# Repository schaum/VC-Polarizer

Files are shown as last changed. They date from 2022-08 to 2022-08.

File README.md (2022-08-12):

# VC-Polarizer

This VC Polarizer hardware is a shrinked clone of the [Mutable Blinds PCB](http://mutable-instruments.net/modules/blinds) and published under the same license: cc-by-sa-3.0.

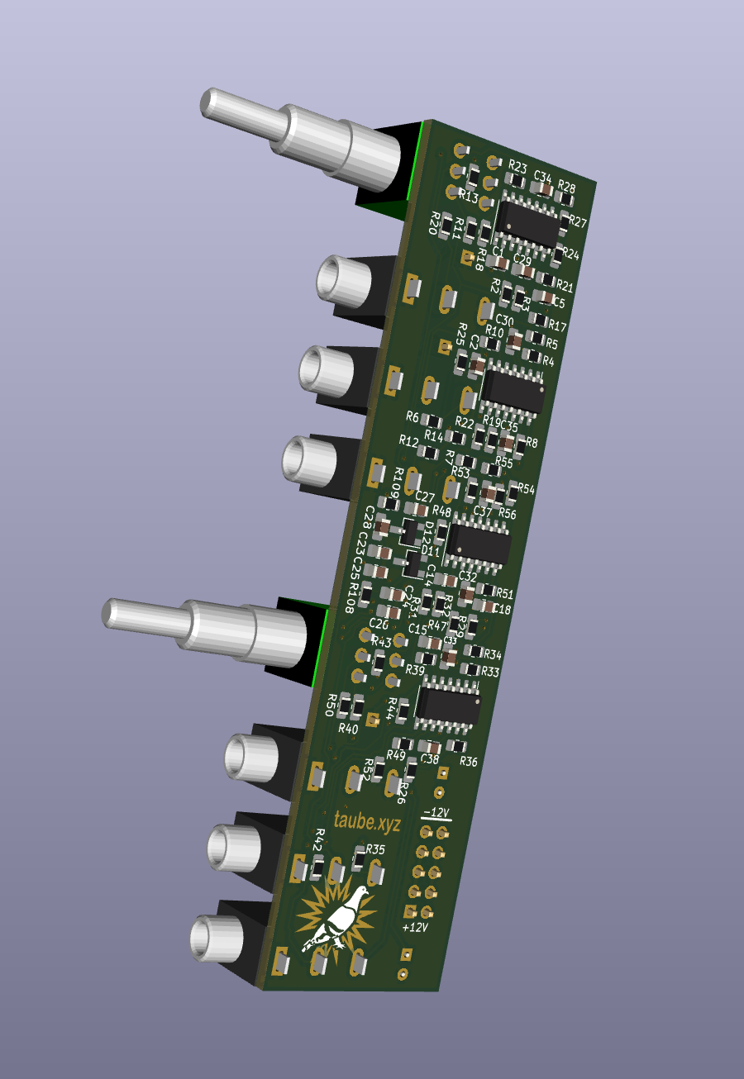
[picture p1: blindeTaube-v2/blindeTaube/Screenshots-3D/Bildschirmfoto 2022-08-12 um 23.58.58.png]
screenshot back side

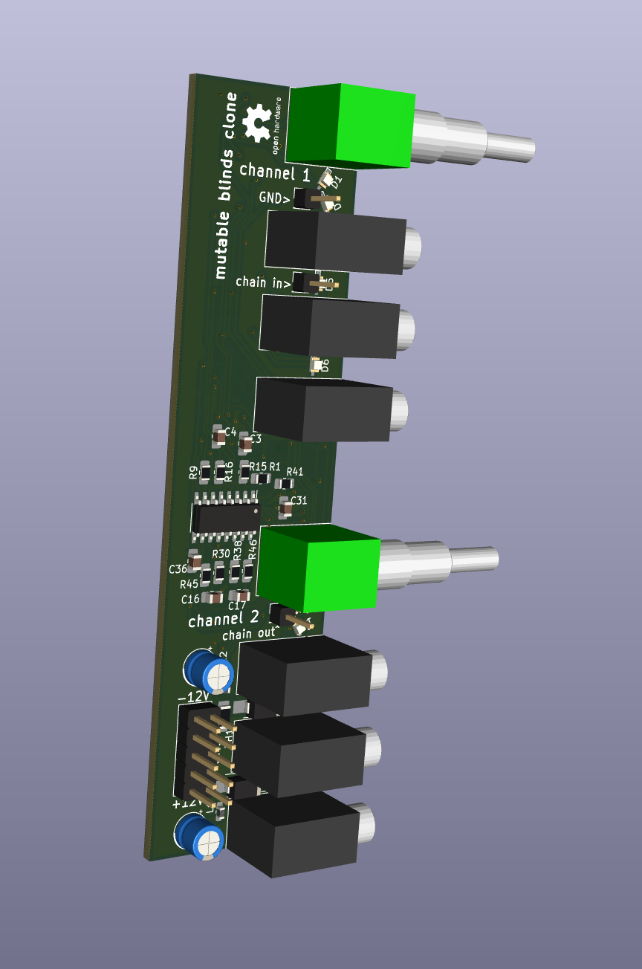
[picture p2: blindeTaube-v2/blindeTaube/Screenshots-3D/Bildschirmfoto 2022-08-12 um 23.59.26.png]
screenshot front side


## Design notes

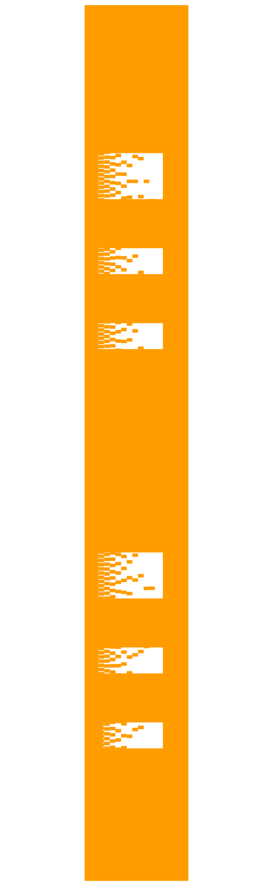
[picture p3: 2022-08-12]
blindeTaube-v2/design/design-FrontPanel-FCU.jpg

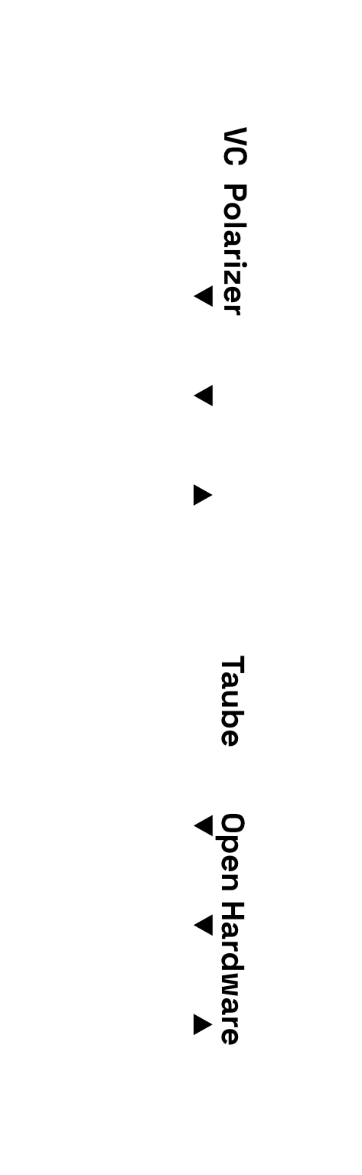
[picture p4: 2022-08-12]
blindeTaube-v2/design/design-FrontPanel-FSilk.jpg

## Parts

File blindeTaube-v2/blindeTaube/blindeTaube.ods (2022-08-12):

Source: | /Users/urbs/Documents/UrbsEleDev-DIY/03Elektronik_Projekte/211212blindeTaube-BlindsKlon/blindeTaube/blindeTaube.kicad_sch
Date: | 2022 April 15, Friday 16:03:00
Tool: | Eeschema (6.0.2-0)
Generator: | /Applications/KiCad/KiCad.app/Contents/SharedSupport/plugins/bom_csv_grouped_by_value.py
Component Count: | 199
Individual Components:
Item | Qty | Reference(s) | Value | LibPart | Footprint | Datasheet
 |  | C1 | 47p | Device:C | Capacitor_SMD:C_0805_2012Metric_Pad1.18x1.45mm_HandSolder | ~
 |  | C2 | 47p | Device:C | Capacitor_SMD:C_0805_2012Metric_Pad1.18x1.45mm_HandSolder | ~
 |  | C3 | 560p | Device:C | Capacitor_SMD:C_0805_2012Metric_Pad1.18x1.45mm_HandSolder | ~
 |  | C4 | 560p | Device:C | Capacitor_SMD:C_0805_2012Metric_Pad1.18x1.45mm_HandSolder | ~
 |  | C5 | 47p | Device:C | Capacitor_SMD:C_0805_2012Metric_Pad1.18x1.45mm_HandSolder | ~
 |  | C6 | 47p | Device:C | Capacitor_SMD:C_0805_2012Metric_Pad1.18x1.45mm_HandSolder | ~
 |  | C7 | 47p | Device:C | Capacitor_SMD:C_0805_2012Metric_Pad1.18x1.45mm_HandSolder | ~
 |  | C8 | 560p | Device:C | Capacitor_SMD:C_0805_2012Metric_Pad1.18x1.45mm_HandSolder | ~
 |  | C9 | 560p | Device:C | Capacitor_SMD:C_0805_2012Metric_Pad1.18x1.45mm_HandSolder | ~
 |  | C10 | 47p | Device:C | Capacitor_SMD:C_0805_2012Metric_Pad1.18x1.45mm_HandSolder | ~
 |  | C11 | 47p | Device:C | Capacitor_SMD:C_0805_2012Metric_Pad1.18x1.45mm_HandSolder | ~
 |  | C12 | 47p | Device:C | Capacitor_SMD:C_0805_2012Metric_Pad1.18x1.45mm_HandSolder | ~
 |  | C13 | 560p | Device:C | Capacitor_SMD:C_0805_2012Metric_Pad1.18x1.45mm_HandSolder | ~
 |  | C14 | 47p | Device:C | Capacitor_SMD:C_0805_2012Metric_Pad1.18x1.45mm_HandSolder | ~
 |  | C15 | 47p | Device:C | Capacitor_SMD:C_0805_2012Metric_Pad1.18x1.45mm_HandSolder | ~
 |  | C16 | 560p | Device:C | Capacitor_SMD:C_0805_2012Metric_Pad1.18x1.45mm_HandSolder | ~
 |  | C17 | 560p | Device:C | Capacitor_SMD:C_0805_2012Metric_Pad1.18x1.45mm_HandSolder | ~
 |  | C18 | 47p | Device:C | Capacitor_SMD:C_0805_2012Metric_Pad1.18x1.45mm_HandSolder | ~
 |  | C19 | 560p | Device:C | Capacitor_SMD:C_0805_2012Metric_Pad1.18x1.45mm_HandSolder | ~
 |  | C20 | 47p | Device:C | Capacitor_SMD:C_0805_2012Metric_Pad1.18x1.45mm_HandSolder | ~
 |  | C21 | 22u | Device:C_Polarized | Capacitor_THT:CP_Radial_D5.0mm_P2.50mm | ~
 |  | C22 | 22u | Device:C_Polarized | Capacitor_THT:CP_Radial_D5.0mm_P2.50mm | ~
 |  | C23 | 100n | Device:C | Capacitor_SMD:C_0805_2012Metric_Pad1.18x1.45mm_HandSolder | ~
 |  | C24 | 100n | Device:C | Capacitor_SMD:C_0805_2012Metric_Pad1.18x1.45mm_HandSolder | ~
 |  | C25 | 100n | Device:C | Capacitor_SMD:C_0805_2012Metric_Pad1.18x1.45mm_HandSolder | ~
 |  | C26 | 100n | Device:C | Capacitor_SMD:C_0805_2012Metric_Pad1.18x1.45mm_HandSolder | ~
 |  | C27 | 100n | Device:C | Capacitor_SMD:C_0805_2012Metric_Pad1.18x1.45mm_HandSolder | ~
 |  | C28 | 100n | Device:C | Capacitor_SMD:C_0805_2012Metric_Pad1.18x1.45mm_HandSolder | ~
 |  | C29 | 100n | Device:C | Capacitor_SMD:C_0805_2012Metric_Pad1.18x1.45mm_HandSolder | ~
 |  | C30 | 100n | Device:C | Capacitor_SMD:C_0805_2012Metric_Pad1.18x1.45mm_HandSolder | ~
 |  | C31 | 100n | Device:C | Capacitor_SMD:C_0805_2012Metric_Pad1.18x1.45mm_HandSolder | ~
 |  | C32 | 100n | Device:C | Capacitor_SMD:C_0805_2012Metric_Pad1.18x1.45mm_HandSolder | ~
 |  | C33 | 100n | Device:C | Capacitor_SMD:C_0805_2012Metric_Pad1.18x1.45mm_HandSolder | ~
 |  | C34 | 100n | Device:C | Capacitor_SMD:C_0805_2012Metric_Pad1.18x1.45mm_HandSolder | ~
 |  | C35 | 100n | Device:C | Capacitor_SMD:C_0805_2012Metric_Pad1.18x1.45mm_HandSolder | ~
 |  | C36 | 100n | Device:C | Capacitor_SMD:C_0805_2012Metric_Pad1.18x1.45mm_HandSolder | ~
 |  | C37 | 100n | Device:C | Capacitor_SMD:C_0805_2012Metric_Pad1.18x1.45mm_HandSolder | ~
 |  | C38 | 100n | Device:C | Capacitor_SMD:C_0805_2012Metric_Pad1.18x1.45mm_HandSolder | ~
 |  | C39 | 100n | Device:C | Capacitor_SMD:C_0805_2012Metric_Pad1.18x1.45mm_HandSolder | ~
 |  | C40 | 100n | Device:C | Capacitor_SMD:C_0805_2012Metric_Pad1.18x1.45mm_HandSolder | ~
 |  | C41 | 100n | Device:C | Capacitor_SMD:C_0805_2012Metric_Pad1.18x1.45mm_HandSolder | ~
 |  | C42 | 100n | Device:C | Capacitor_SMD:C_0805_2012Metric_Pad1.18x1.45mm_HandSolder | ~
 |  | C43 | 100n | Device:C | Capacitor_SMD:C_0805_2012Metric_Pad1.18x1.45mm_HandSolder | ~
 |  | C44 | 100n | Device:C | Capacitor_SMD:C_0805_2012Metric_Pad1.18x1.45mm_HandSolder | ~
 |  | C45 | 100n | Device:C | Capacitor_SMD:C_0805_2012Metric_Pad1.18x1.45mm_HandSolder | ~
 |  | C46 | 100n | Device:C | Capacitor_SMD:C_0805_2012Metric_Pad1.18x1.45mm_HandSolder | ~
 |  | C47 | 100n | Device:C | Capacitor_SMD:C_0805_2012Metric_Pad1.18x1.45mm_HandSolder | ~
 |  | C48 | 100n | Device:C | Capacitor_SMD:C_0805_2012Metric_Pad1.18x1.45mm_HandSolder | ~
 |  | D1 | LED_Dual_AKKA>AK-vertauscht-aber geht so | Device:LED_Dual_AKKA | LED_SMD:LED_Avago_PLCC4_3.2x2.8mm_CW | ~
 |  | D2 | LED_Dual_AKKA>AK-vertauscht-aber geht so | Device:LED_Dual_AKKA | LED_SMD:LED_Avago_PLCC4_3.2x2.8mm_CW | ~
 |  | D3 | LED_Dual_AKKA>AK-vertauscht-aber geht so | Device:LED_Dual_AKKA | LED_SMD:LED_Avago_PLCC4_3.2x2.8mm_CW | ~
 |  | D4 | LED_Dual_AKKA>AK-vertauscht-aber geht so | Device:LED_Dual_AKKA | LED_SMD:LED_Avago_PLCC4_3.2x2.8mm_CW | ~
 |  | D5 | LED_Dual_AKKA>AK-vertauscht-aber geht so | Device:LED_Dual_AKKA | LED_SMD:LED_Avago_PLCC4_3.2x2.8mm_CW | ~
 |  | D6 | LED_Dual_AKKA>AK-vertauscht-aber geht so | Device:LED_Dual_AKKA | LED_SMD:LED_Avago_PLCC4_3.2x2.8mm_CW | ~
 |  | D7 | LED_Dual_AKKA>AK-vertauscht-aber geht so | Device:LED_Dual_AKKA | LED_SMD:LED_Avago_PLCC4_3.2x2.8mm_CW | ~
 |  | D8 | LED_Dual_AKKA>AK-vertauscht-aber geht so | Device:LED_Dual_AKKA | LED_SMD:LED_Avago_PLCC4_3.2x2.8mm_CW | ~
 |  | D9 | D | Device:D | Diode_SMD:D_MELF_Handsoldering | ~
 |  | D10 | D | Device:D | Diode_SMD:D_MELF_Handsoldering | ~
 |  | D11 | LM4040DBZ-10 | Reference_Voltage:LM4040DBZ-10 | Package_TO_SOT_SMD:SOT-23_Handsoldering | http://www.ti.com/lit/ds/symlink/lm4040-n.pdf
 |  | D12 | LM4040DBZ-10 | Reference_Voltage:LM4040DBZ-10 | Package_TO_SOT_SMD:SOT-23_Handsoldering | http://www.ti.com/lit/ds/symlink/lm4040-n.pdf
 |  | J1 | AudioJack2_SwitchT | Connector:AudioJack2_SwitchT | urbsLib:Jack_3.5mm_QingPu_distant | ~
 |  | J2 | AudioJack2_SwitchT | Connector:AudioJack2_SwitchT | urbsLib:Jack_3.5mm_QingPu_distant | ~
 |  | J3 | AudioJack2_SwitchT | Connector:AudioJack2_SwitchT | urbsLib:Jack_3.5mm_QingPu_distant | ~
 |  | J4 | AudioJack2_SwitchT | Connector:AudioJack2_SwitchT | urbsLib:Jack_3.5mm_QingPu_distant | ~
 |  | J5 | AudioJack2_SwitchT | Connector:AudioJack2_SwitchT | urbsLib:Jack_3.5mm_QingPu_distant | ~
 |  | J6 | AudioJack2_SwitchT | Connector:AudioJack2_SwitchT | urbsLib:Jack_3.5mm_QingPu_distant | ~
 |  | J7 | AudioJack2_SwitchT | Connector:AudioJack2_SwitchT | urbsLib:Jack_3.5mm_QingPu_distant | ~
 |  | J8 | AudioJack2_SwitchT | Connector:AudioJack2_SwitchT | urbsLib:Jack_3.5mm_QingPu_distant | ~
 |  | J9 | AudioJack2_SwitchT | Connector:AudioJack2_SwitchT | urbsLib:Jack_3.5mm_QingPu_distant | ~
 |  | J10 | AudioJack2_SwitchT | Connector:AudioJack2_SwitchT | urbsLib:Jack_3.5mm_QingPu_distant | ~
 |  | J11 | AudioJack2_SwitchT | Connector:AudioJack2_SwitchT | urbsLib:Jack_3.5mm_QingPu_distant | ~
 |  | J12 | AudioJack2_SwitchT | Connector:AudioJack2_SwitchT | urbsLib:Jack_3.5mm_QingPu_distant | ~
 |  | J13 | Conn_02x05_Odd_Even | Connector_Generic:Conn_02x05_Odd_Even | Connector_PinHeader_2.54mm:PinHeader_2x05_P2.54mm_Vertical | ~
 |  | L1 | 742792664 | Device:L | Inductor_SMD:L_1008_2520Metric_Pad1.43x2.20mm_HandSolder | ~
 |  | L2 | 742792664 | Device:L | Inductor_SMD:L_1008_2520Metric_Pad1.43x2.20mm_HandSolder | ~
 |  | R1 | 100k | Device:R | Resistor_SMD:R_0805_2012Metric_Pad1.20x1.40mm_HandSolder | ~
 |  | R2 | 100k | Device:R | Resistor_SMD:R_0805_2012Metric_Pad1.20x1.40mm_HandSolder | ~
 |  | R3 | 100k | Device:R | Resistor_SMD:R_0805_2012Metric_Pad1.20x1.40mm_HandSolder | ~
 |  | R4 | 4k3 | Device:R | Resistor_SMD:R_0805_2012Metric_Pad1.20x1.40mm_HandSolder | ~
 |  | R5 | 4k3 | Device:R | Resistor_SMD:R_0805_2012Metric_Pad1.20x1.40mm_HandSolder | ~
 |  | R6 | 100k | Device:R | Resistor_SMD:R_0805_2012Metric_Pad1.20x1.40mm_HandSolder | ~
 |  | R7 | 3k9 | Device:R | Resistor_SMD:R_0805_2012Metric_Pad1.20x1.40mm_HandSolder | ~
 |  | R8 | 4k3 | Device:R | Resistor_SMD:R_0805_2012Metric_Pad1.20x1.40mm_HandSolder | ~
 |  | R9 | 33k2 | Device:R | Resistor_SMD:R_0805_2012Metric_Pad1.20x1.40mm_HandSolder | ~
 |  | R10 | 66k5 | Device:R | Resistor_SMD:R_0805_2012Metric_Pad1.20x1.40mm_HandSolder | ~
 |  | R11 | 205k | Device:R | Resistor_SMD:R_0805_2012Metric_Pad1.20x1.40mm_HandSolder | ~
 |  | R12 | 402 | Device:R | Resistor_SMD:R_0805_2012Metric_Pad1.20x1.40mm_HandSolder | ~
 |  | R13 | 100k | Device:R | Resistor_SMD:R_0805_2012Metric_Pad1.20x1.40mm_HandSolder | ~
 |  | R14 | 1M | Device:R | Resistor_SMD:R_0805_2012Metric_Pad1.20x1.40mm_HandSolder | ~
 |  | R15 | 510 | Device:R | Resistor_SMD:R_0805_2012Metric_Pad1.20x1.40mm_HandSolder | ~
 |  | R16 | 510 | Device:R | Resistor_SMD:R_0805_2012Metric_Pad1.20x1.40mm_HandSolder | ~
 |  | R17 | 33k2 | Device:R | Resistor_SMD:R_0805_2012Metric_Pad1.20x1.40mm_HandSolder | ~
 |  | R18 | 100k | Device:R | Resistor_SMD:R_0805_2012Metric_Pad1.20x1.40mm_HandSolder | ~
 |  | R19 | 1M | Device:R | Resistor_SMD:R_0805_2012Metric_Pad1.20x1.40mm_HandSolder | ~
 |  | R20 | 100k | Device:R | Resistor_SMD:R_0805_2012Metric_Pad1.20x1.40mm_HandSolder | ~
 |  | R21 | 100k | Device:R | Resistor_SMD:R_0805_2012Metric_Pad1.20x1.40mm_HandSolder | ~
 |  | R22 | 1k2 | Device:R | Resistor_SMD:R_0805_2012Metric_Pad1.20x1.40mm_HandSolder | ~
 |  | R23 | 100k | Device:R | Resistor_SMD:R_0805_2012Metric_Pad1.20x1.40mm_HandSolder | ~
 |  | R24 | 1M | Device:R | Resistor_SMD:R_0805_2012Metric_Pad1.20x1.40mm_HandSolder | ~
 |  | R25 | 66k5 | Device:R | Resistor_SMD:R_0805_2012Metric_Pad1.20x1.40mm_HandSolder | ~
 |  | R26 | 100k | Device:R | Resistor_SMD:R_0805_2012Metric_Pad1.20x1.40mm_HandSolder | ~
 |  | R27 | 1M | Device:R | Resistor_SMD:R_0805_2012Metric_Pad1.20x1.40mm_HandSolder | ~
 |  | R28 | 1k2 | Device:R | Resistor_SMD:R_0805_2012Metric_Pad1.20x1.40mm_HandSolder | ~
 |  | R29 | 66k5 | Device:R | Resistor_SMD:R_0805_2012Metric_Pad1.20x1.40mm_HandSolder | ~
 |  | R30 | 100k | Device:R | Resistor_SMD:R_0805_2012Metric_Pad1.20x1.40mm_HandSolder | ~
 |  | R31 | 100k | Device:R | Resistor_SMD:R_0805_2012Metric_Pad1.20x1.40mm_HandSolder | ~
 |  | R32 | 100k | Device:R | Resistor_SMD:R_0805_2012Metric_Pad1.20x1.40mm_HandSolder | ~
 |  | R33 | 4k3 | Device:R | Resistor_SMD:R_0805_2012Metric_Pad1.20x1.40mm_HandSolder | ~
 |  | R34 | 4k3 | Device:R | Resistor_SMD:R_0805_2012Metric_Pad1.20x1.40mm_HandSolder | ~
 |  | R35 | 100k | Device:R | Resistor_SMD:R_0805_2012Metric_Pad1.20x1.40mm_HandSolder | ~
 |  | R36 | 3k9 | Device:R | Resistor_SMD:R_0805_2012Metric_Pad1.20x1.40mm_HandSolder | ~
 |  | R37 | 4k3 | Device:R | Resistor_SMD:R_0805_2012Metric_Pad1.20x1.40mm_HandSolder | ~
 |  | R38 | 33k2 | Device:R | Resistor_SMD:R_0805_2012Metric_Pad1.20x1.40mm_HandSolder | ~
 |  | R39 | 66k5 | Device:R | Resistor_SMD:R_0805_2012Metric_Pad1.20x1.40mm_HandSolder | ~
 |  | R40 | 205k | Device:R | Resistor_SMD:R_0805_2012Metric_Pad1.20x1.40mm_HandSolder | ~
 |  | R41 | DNP | Device:R | Resistor_SMD:R_0805_2012Metric_Pad1.20x1.40mm_HandSolder | ~
 |  | R42 | 402 | Device:R | Resistor_SMD:R_0805_2012Metric_Pad1.20x1.40mm_HandSolder | ~
 |  | R43 | 100k | Device:R | Resistor_SMD:R_0805_2012Metric_Pad1.20x1.40mm_HandSolder | ~
 |  | R44 | 1M | Device:R | Resistor_SMD:R_0805_2012Metric_Pad1.20x1.40mm_HandSolder | ~
 |  | R45 | 510 | Device:R | Resistor_SMD:R_0805_2012Metric_Pad1.20x1.40mm_HandSolder | ~
 |  | R46 | 510 | Device:R | Resistor_SMD:R_0805_2012Metric_Pad1.20x1.40mm_HandSolder | ~
 |  | R47 | 33k2 | Device:R | Resistor_SMD:R_0805_2012Metric_Pad1.20x1.40mm_HandSolder | ~
 |  | R48 | 100k | Device:R | Resistor_SMD:R_0805_2012Metric_Pad1.20x1.40mm_HandSolder | ~
 |  | R49 | 1M | Device:R | Resistor_SMD:R_0805_2012Metric_Pad1.20x1.40mm_HandSolder | ~
 |  | R50 | 100k | Device:R | Resistor_SMD:R_0805_2012Metric_Pad1.20x1.40mm_HandSolder | ~
 |  | R51 | 100k | Device:R | Resistor_SMD:R_0805_2012Metric_Pad1.20x1.40mm_HandSolder | ~
 |  | R52 | 1k2 | Device:R | Resistor_SMD:R_0805_2012Metric_Pad1.20x1.40mm_HandSolder | ~
 |  | R53 | 100k | Device:R | Resistor_SMD:R_0805_2012Metric_Pad1.20x1.40mm_HandSolder | ~
 |  | R54 | 1M | Device:R | Resistor_SMD:R_0805_2012Metric_Pad1.20x1.40mm_HandSolder | ~
 |  | R55 | 1M | Device:R | Resistor_SMD:R_0805_2012Metric_Pad1.20x1.40mm_HandSolder | ~
 |  | R56 | 1k2 | Device:R | Resistor_SMD:R_0805_2012Metric_Pad1.20x1.40mm_HandSolder | ~
 |  | R57 | 100k | Device:R | Resistor_SMD:R_0805_2012Metric_Pad1.20x1.40mm_HandSolder | ~
 |  | R58 | 100k | Device:R | Resistor_SMD:R_0805_2012Metric_Pad1.20x1.40mm_HandSolder | ~
 |  | R59 | 4k3 | Device:R | Resistor_SMD:R_0805_2012Metric_Pad1.20x1.40mm_HandSolder | ~
 |  | R60 | 4k3 | Device:R | Resistor_SMD:R_0805_2012Metric_Pad1.20x1.40mm_HandSolder | ~
 |  | R61 | 100k | Device:R | Resistor_SMD:R_0805_2012Metric_Pad1.20x1.40mm_HandSolder | ~
 |  | R62 | 3k9 | Device:R | Resistor_SMD:R_0805_2012Metric_Pad1.20x1.40mm_HandSolder | ~
 |  | R63 | 4k3 | Device:R | Resistor_SMD:R_0805_2012Metric_Pad1.20x1.40mm_HandSolder | ~
 |  | R64 | 33k2 | Device:R | Resistor_SMD:R_0805_2012Metric_Pad1.20x1.40mm_HandSolder | ~
 |  | R65 | 66k5 | Device:R | Resistor_SMD:R_0805_2012Metric_Pad1.20x1.40mm_HandSolder | ~
 |  | R66 | 205k | Device:R | Resistor_SMD:R_0805_2012Metric_Pad1.20x1.40mm_HandSolder | ~
 |  | R67 | 402 | Device:R | Resistor_SMD:R_0805_2012Metric_Pad1.20x1.40mm_HandSolder | ~
 |  | R68 | 100k | Device:R | Resistor_SMD:R_0805_2012Metric_Pad1.20x1.40mm_HandSolder | ~
 |  | R69 | 1M | Device:R | Resistor_SMD:R_0805_2012Metric_Pad1.20x1.40mm_HandSolder | ~
 |  | R70 | 510 | Device:R | Resistor_SMD:R_0805_2012Metric_Pad1.20x1.40mm_HandSolder | ~
 |  | R71 | 510 | Device:R | Resistor_SMD:R_0805_2012Metric_Pad1.20x1.40mm_HandSolder | ~
 |  | R72 | 33k2 | Device:R | Resistor_SMD:R_0805_2012Metric_Pad1.20x1.40mm_HandSolder | ~
 |  | R73 | 100k | Device:R | Resistor_SMD:R_0805_2012Metric_Pad1.20x1.40mm_HandSolder | ~
 |  | R74 | 1M | Device:R | Resistor_SMD:R_0805_2012Metric_Pad1.20x1.40mm_HandSolder | ~
 |  | R75 | 100k | Device:R | Resistor_SMD:R_0805_2012Metric_Pad1.20x1.40mm_HandSolder | ~
 |  | R76 | 100k | Device:R | Resistor_SMD:R_0805_2012Metric_Pad1.20x1.40mm_HandSolder | ~
 |  | R77 | 1k2 | Device:R | Resistor_SMD:R_0805_2012Metric_Pad1.20x1.40mm_HandSolder | ~
 |  | R78 | 100k | Device:R | Resistor_SMD:R_0805_2012Metric_Pad1.20x1.40mm_HandSolder | ~
 |  | R79 | 1M | Device:R | Resistor_SMD:R_0805_2012Metric_Pad1.20x1.40mm_HandSolder | ~
 |  | R80 | 1M | Device:R | Resistor_SMD:R_0805_2012Metric_Pad1.20x1.40mm_HandSolder | ~
 |  | R81 | 1k2 | Device:R | Resistor_SMD:R_0805_2012Metric_Pad1.20x1.40mm_HandSolder | ~
 |  | R82 | 66k5 | Device:R | Resistor_SMD:R_0805_2012Metric_Pad1.20x1.40mm_HandSolder | ~
 |  | R83 | 100k | Device:R | Resistor_SMD:R_0805_2012Metric_Pad1.20x1.40mm_HandSolder | ~
 |  | R84 | 100k | Device:R | Resistor_SMD:R_0805_2012Metric_Pad1.20x1.40mm_HandSolder | ~
 |  | R85 | 100k | Device:R | Resistor_SMD:R_0805_2012Metric_Pad1.20x1.40mm_HandSolder | ~
 |  | R86 | 4k3 | Device:R | Resistor_SMD:R_0805_2012Metric_Pad1.20x1.40mm_HandSolder | ~
 |  | R87 | 4k3 | Device:R | Resistor_SMD:R_0805_2012Metric_Pad1.20x1.40mm_HandSolder | ~
 |  | R88 | 100k | Device:R | Resistor_SMD:R_0805_2012Metric_Pad1.20x1.40mm_HandSolder | ~
 |  | R89 | 33k2 | Device:R | Resistor_SMD:R_0805_2012Metric_Pad1.20x1.40mm_HandSolder | ~
 |  | R90 | 66k5 | Device:R | Resistor_SMD:R_0805_2012Metric_Pad1.20x1.40mm_HandSolder | ~
 |  | R91 | 205k | Device:R | Resistor_SMD:R_0805_2012Metric_Pad1.20x1.40mm_HandSolder | ~
 |  | R92 | DNP | Device:R | Resistor_SMD:R_0805_2012Metric_Pad1.20x1.40mm_HandSolder | ~
 |  | R93 | 402 | Device:R | Resistor_SMD:R_0805_2012Metric_Pad1.20x1.40mm_HandSolder | ~
 |  | R94 | 100k | Device:R | Resistor_SMD:R_0805_2012Metric_Pad1.20x1.40mm_HandSolder | ~
 |  | R95 | 1M | Device:R | Resistor_SMD:R_0805_2012Metric_Pad1.20x1.40mm_HandSolder | ~
 |  | R96 | 510 | Device:R | Resistor_SMD:R_0805_2012Metric_Pad1.20x1.40mm_HandSolder | ~
 |  | R97 | 510 | Device:R | Resistor_SMD:R_0805_2012Metric_Pad1.20x1.40mm_HandSolder | ~
 |  | R98 | 33k2 | Device:R | Resistor_SMD:R_0805_2012Metric_Pad1.20x1.40mm_HandSolder | ~
 |  | R99 | 100k | Device:R | Resistor_SMD:R_0805_2012Metric_Pad1.20x1.40mm_HandSolder | ~
 |  | R100 | 1M | Device:R | Resistor_SMD:R_0805_2012Metric_Pad1.20x1.40mm_HandSolder | ~
 |  | R101 | 100k | Device:R | Resistor_SMD:R_0805_2012Metric_Pad1.20x1.40mm_HandSolder | ~
 |  | R102 | 100k | Device:R | Resistor_SMD:R_0805_2012Metric_Pad1.20x1.40mm_HandSolder | ~
 |  | R103 | 1k2 | Device:R | Resistor_SMD:R_0805_2012Metric_Pad1.20x1.40mm_HandSolder | ~
 |  | R104 | 100k | Device:R | Resistor_SMD:R_0805_2012Metric_Pad1.20x1.40mm_HandSolder | ~
 |  | R105 | 1M | Device:R | Resistor_SMD:R_0805_2012Metric_Pad1.20x1.40mm_HandSolder | ~
 |  | R106 | 1M | Device:R | Resistor_SMD:R_0805_2012Metric_Pad1.20x1.40mm_HandSolder | ~
 |  | R107 | 1k2 | Device:R | Resistor_SMD:R_0805_2012Metric_Pad1.20x1.40mm_HandSolder | ~
 |  | R108 | 1k2 | Device:R | Resistor_SMD:R_0805_2012Metric_Pad1.20x1.40mm_HandSolder | ~
 |  | R109 | 1k2 | Device:R | Resistor_SMD:R_0805_2012Metric_Pad1.20x1.40mm_HandSolder | ~
 |  | RV1 | 10kB | Device:R_Potentiometer_Dual_Separate | urbsLib:RK097-dual-top | ~
 |  | RV2 | 10kB | Device:R_Potentiometer_Dual_Separate | urbsLib:RK097-dual-top | ~
 |  | RV3 | 10kB | Device:R_Potentiometer_Dual_Separate | urbsLib:RK097-dual-top | ~
 |  | RV4 | 10kB | Device:R_Potentiometer_Dual_Separate | urbsLib:RK097-dual-top | ~
 |  | TH1 | Thermistor_PTC | Device:Thermistor_PTC | Resistor_SMD:R_0805_2012Metric_Pad1.20x1.40mm_HandSolder | ~
 |  | U1 | OPA4171 | Amplifier_Operational:OPA4134 | Package_SO:TSSOP-14_4.4x5mm_P0.65mm | http://www.ti.com/lit/ds/symlink/opa134.pdf
 |  | U2 | OPA4171 | Amplifier_Operational:OPA4134 | Package_SO:TSSOP-14_4.4x5mm_P0.65mm | http://www.ti.com/lit/ds/symlink/opa134.pdf
 |  | U3 | SSI2164 | Audio:SSI2164 | Package_SO:SOIC-16_3.9x9.9mm_P1.27mm | http://www.soundsemiconductor.com/downloads/ssi2164datasheet.pdf
 |  | U4 | OPA4171 | Amplifier_Operational:OPA4134 | Package_SO:TSSOP-14_4.4x5mm_P0.65mm | http://www.ti.com/lit/ds/symlink/opa134.pdf
 |  | U5 | OPA4171 | Amplifier_Operational:OPA4134 | Package_SO:TSSOP-14_4.4x5mm_P0.65mm | http://www.ti.com/lit/ds/symlink/opa134.pdf
 |  | U6 | OPA4171 | Amplifier_Operational:OPA4134 | Package_SO:TSSOP-14_4.4x5mm_P0.65mm | http://www.ti.com/lit/ds/symlink/opa134.pdf
 |  | U7 | OPA4171 | Amplifier_Operational:OPA4134 | Package_SO:TSSOP-14_4.4x5mm_P0.65mm | http://www.ti.com/lit/ds/symlink/opa134.pdf
 |  | U8 | SSI2164 | Audio:SSI2164 | Package_SO:SOIC-16_3.9x9.9mm_P1.27mm | http://www.soundsemiconductor.com/downloads/ssi2164datasheet.pdf
 |  | U9 | OPA4171 | Amplifier_Operational:OPA4134 | Package_SO:TSSOP-14_4.4x5mm_P0.65mm | http://www.ti.com/lit/ds/symlink/opa134.pdf
 |  | U10 | OPA4171 | Amplifier_Operational:OPA4134 | Package_SO:TSSOP-14_4.4x5mm_P0.65mm | http://www.ti.com/lit/ds/symlink/opa134.pdf
Collated Components:
Item | Qty | Reference(s) | Value | LibPart | Footprint | Datasheet
1 | 12 | C1, C2, C5, C6, C7, C10, C11, C12, C14, C15, C18, C20 | 47p | Device:C | Capacitor_SMD:C_0805_2012Metric_Pad1.18x1.45mm_HandSolder | ~
2 | 8 | C3, C4, C8, C9, C13, C16, C17, C19 | 560p | Device:C | Capacitor_SMD:C_0805_2012Metric_Pad1.18x1.45mm_HandSolder | ~
3 | 2 | C21, C22 | 22u | Device:C_Polarized | Capacitor_THT:CP_Radial_D5.0mm_P2.50mm | ~
4 | 26 | C23, C24, C25, C26, C27, C28, C29, C30, C31, C32, C33, C34, C35, C36, C37, C38, C39, C40, C41, C42, C43, C44, C45, C46, C47, C48 | 100n | Device:C | Capacitor_SMD:C_0805_2012Metric_Pad1.18x1.45mm_HandSolder | ~
5 | 8 | D1, D2, D3, D4, D5, D6, D7, D8 | LED_Dual_AKKA>AK-vertauscht-aber geht so | Device:LED_Dual_AKKA | LED_SMD:LED_Avago_PLCC4_3.2x2.8mm_CW | ~
6 | 2 | D9, D10 | D | Device:D | Diode_SMD:D_MELF_Handsoldering | ~
7 | 2 | D11, D12 | LM4040DBZ-10 | Reference_Voltage:LM4040DBZ-10 | Package_TO_SOT_SMD:SOT-23_Handsoldering | http://www.ti.com/lit/ds/symlink/lm4040-n.pdf
8 | 12 | J1, J2, J3, J4, J5, J6, J7, J8, J9, J10, J11, J12 | AudioJack2_SwitchT | Connector:AudioJack2_SwitchT | urbsLib:Jack_3.5mm_QingPu_distant | ~
9 | 1 | J13 | Conn_02x05_Odd_Even | Connector_Generic:Conn_02x05_Odd_Even | Connector_PinHeader_2.54mm:PinHeader_2x05_P2.54mm_Vertical | ~
10 | 2 | L1, L2 | 742792664 | Device:L | Inductor_SMD:L_1008_2520Metric_Pad1.43x2.20mm_HandSolder | ~
11 | 36 | R1, R2, R3, R6, R13, R18, R20, R21, R23, R26, R30, R31, R32, R35, R43, R48, R50, R51, R53, R57, R58, R61, R68, R73, R75, R76, R78, R83, R84, R85, R88, R94, R99, R101, R102, R104 | 100k | Device:R | Resistor_SMD:R_0805_2012Metric_Pad1.20x1.40mm_HandSolder | ~
12 | 11 | R4, R5, R8, R33, R34, R37, R59, R60, R63, R86, R87 | 4k3 | Device:R | Resistor_SMD:R_0805_2012Metric_Pad1.20x1.40mm_HandSolder | ~
13 | 3 | R7, R36, R62 | 3k9 | Device:R | Resistor_SMD:R_0805_2012Metric_Pad1.20x1.40mm_HandSolder | ~
14 | 8 | R9, R17, R38, R47, R64, R72, R89, R98 | 33k2 | Device:R | Resistor_SMD:R_0805_2012Metric_Pad1.20x1.40mm_HandSolder | ~
15 | 7 | R10, R25, R29, R39, R65, R82, R90 | 66k5 | Device:R | Resistor_SMD:R_0805_2012Metric_Pad1.20x1.40mm_HandSolder | ~
16 | 4 | R11, R40, R66, R91 | 205k | Device:R | Resistor_SMD:R_0805_2012Metric_Pad1.20x1.40mm_HandSolder | ~
17 | 4 | R12, R42, R67, R93 | 402 | Device:R | Resistor_SMD:R_0805_2012Metric_Pad1.20x1.40mm_HandSolder | ~
18 | 16 | R14, R19, R24, R27, R44, R49, R54, R55, R69, R74, R79, R80, R95, R100, R105, R106 | 1M | Device:R | Resistor_SMD:R_0805_2012Metric_Pad1.20x1.40mm_HandSolder | ~
19 | 8 | R15, R16, R45, R46, R70, R71, R96, R97 | 510 | Device:R | Resistor_SMD:R_0805_2012Metric_Pad1.20x1.40mm_HandSolder | ~
20 | 10 | R22, R28, R52, R56, R77, R81, R103, R107, R108, R109 | 1k2 | Device:R | Resistor_SMD:R_0805_2012Metric_Pad1.20x1.40mm_HandSolder | ~
21 | 2 | R41, R92 | DNP | Device:R | Resistor_SMD:R_0805_2012Metric_Pad1.20x1.40mm_HandSolder | ~
22 | 4 | RV1, RV2, RV3, RV4 | 10kB | Device:R_Potentiometer_Dual_Separate | urbsLib:RK097-dual-top | ~
23 | 1 | TH1 | Thermistor_PTC | Device:Thermistor_PTC | Resistor_SMD:R_0805_2012Metric_Pad1.20x1.40mm_HandSolder | ~
24 | 8 | U1, U2, U4, U5, U6, U7, U9, U10 | OPA4171 | Amplifier_Operational:OPA4134 | Package_SO:TSSOP-14_4.4x5mm_P0.65mm | http://www.ti.com/lit/ds/symlink/opa134.pdf
25 | 2 | U3, U8 | SSI2164 | Audio:SSI2164 | Package_SO:SOIC-16_3.9x9.9mm_P1.27mm | http://www.soundsemiconductor.com/downloads/ssi2164datasheet.pdf

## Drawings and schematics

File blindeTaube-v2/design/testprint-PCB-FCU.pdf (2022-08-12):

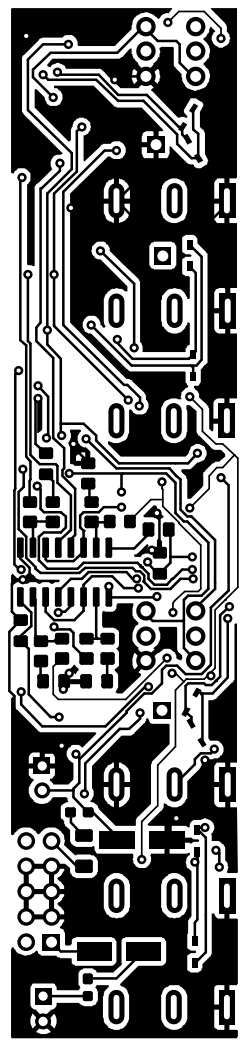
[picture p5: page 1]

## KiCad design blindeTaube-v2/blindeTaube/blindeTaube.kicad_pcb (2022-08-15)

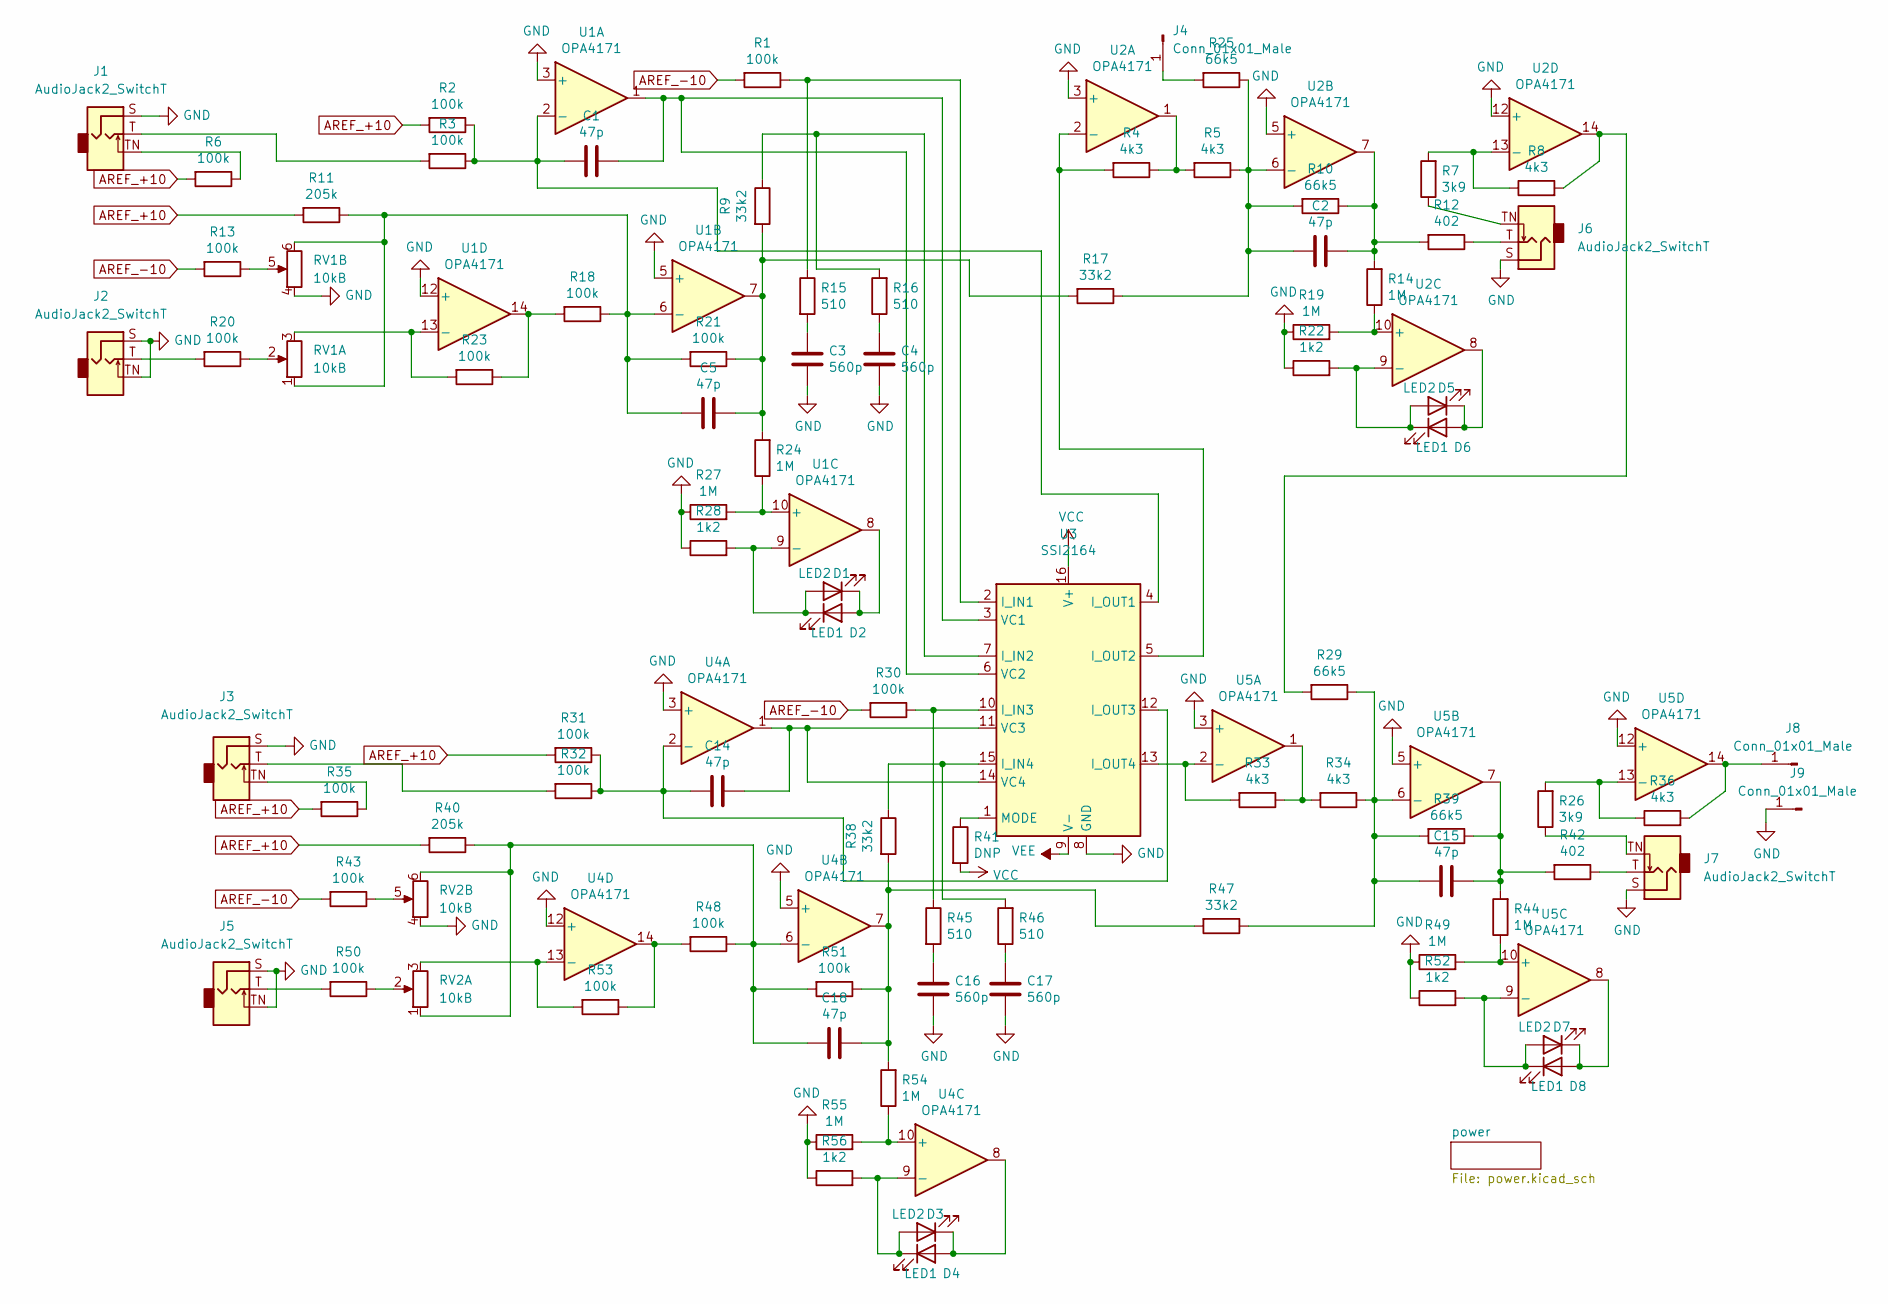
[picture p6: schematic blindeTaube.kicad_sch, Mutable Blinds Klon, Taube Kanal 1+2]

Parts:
C1, C2, C5, C14, C15, C18: 47p; C_0805_2012Metric_Pad1.18x1.45mm_HandSolder
C3, C4, C16, C17: 560p; C_0805_2012Metric_Pad1.18x1.45mm_HandSolder
D1, D3, D5, D7: LED2; LED_2106Metric_Pad1.1x0.5mm_HandSolder
D2, D4, D6, D8: LED1; LED_2106Metric_Pad1.1x0.5mm_HandSolder
J1, J2, J3, J5, J6, J7: AudioJack2_SwitchT; Jack_3.5mm_PJ323_Horizontal
J4, J8, J9: Conn_01x01_Male; PinHeader_1x01_P2.54mm_Vertical
R1, R2, R3, R6, R13, R18, R20, R21, R23, R30, R31, R32, R35, R43, R48, R50, R51, R53: 100k; R_0805_2012Metric_Pad1.20x1.40mm_HandSolder
R4, R5, R8, R33, R34, R36: 4k3; R_0805_2012Metric_Pad1.20x1.40mm_HandSolder
R7, R26: 3k9; R_0805_2012Metric_Pad1.20x1.40mm_HandSolder
R9, R17, R38, R47: 33k2; R_0805_2012Metric_Pad1.20x1.40mm_HandSolder
R10, R25, R29, R39: 66k5; R_0805_2012Metric_Pad1.20x1.40mm_HandSolder
R11, R40: 205k; R_0805_2012Metric_Pad1.20x1.40mm_HandSolder
R12, R42: 402; R_0805_2012Metric_Pad1.20x1.40mm_HandSolder
R14, R19, R24, R27, R44, R49, R54, R55: 1M; R_0805_2012Metric_Pad1.20x1.40mm_HandSolder
R15, R16, R45, R46: 510; R_0805_2012Metric_Pad1.20x1.40mm_HandSolder
R22, R28, R52, R56: 1k2; R_0805_2012Metric_Pad1.20x1.40mm_HandSolder
R41: DNP; R_0805_2012Metric_Pad1.20x1.40mm_HandSolder
RV1, RV2: 10kB; Potentiometer_Alps_RK097_Dual_Horizontal
U1, U2, U4, U5: OPA4171; SOIC-14_3.9x8.7mm_P1.27mm
U3: SSI2164; SOIC-16_3.9x9.9mm_P1.27mm

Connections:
AREF_+10: R2.2, R6.2, R11.2, R31.2, R35.2, R40.2; also elsewhere on the board
AREF_-10: R1.2, R13.2, R30.2, R43.2; also elsewhere on the board
GND: C3.1, C4.1, C16.1, C17.1, J1.S, J2.S, J2.TN, J3.S, J5.S, J5.TN, J6.S, J7.S, J9.1, R19.1, R22.1, R27.1, R28.1, R49.1, R52.1, R55.1, R56.1, RV1.4, RV2.4, U1.3 (+), U1.5 (+), U1.12 (+), U2.3 (+), U2.5 (+), U2.12 (+), U3.8 (GND), U4.3 (+), U4.5 (+), U4.12 (+), U5.3 (+), U5.5 (+), U5.12 (+); also elsewhere on the board
unnamed: C1.1, U1.1, U3.3 (VC1), U3.6 (VC2)
unnamed: C1.2, R2.1, R3.1, U1.2 (-), U3.4 (I_OUT1)
unnamed: C2.1, R10.1, R12.2, R14.2, U2.7
unnamed: C2.2, R5.1, R10.2, R17.1, R25.1, U2.6 (-)
unnamed: C3.2, R15.2
unnamed: C4.2, R16.1
unnamed: C5.1, R9.2, R17.2, R21.1, R24.2, U1.7
unnamed: C5.2, R11.1, R18.1, R21.2, RV1.1, RV1.6, U1.6 (-)
unnamed: C14.1, U3.11 (VC3), U3.14 (VC4), U4.1
unnamed: C14.2, R31.1, R32.1, U3.12 (I_OUT3), U4.2 (-)
unnamed: C15.1, R39.1, R42.2, R44.2, U5.7
unnamed: C15.2, R29.1, R34.1, R39.2, R47.1, U5.6 (-)
unnamed: C16.2, R45.2
unnamed: C17.2, R46.1
unnamed: C18.1, R38.2, R47.2, R51.1, R54.2, U4.7
unnamed: C18.2, R40.1, R48.1, R51.2, RV2.1, RV2.6, U4.6 (-)
unnamed: D1.1 (K), D2.2 (A), U1.8
unnamed: D1.2 (A), D2.1 (K), R28.2, U1.9 (-)
unnamed: D3.1 (K), D4.2 (A), U4.8
unnamed: D3.2 (A), D4.1 (K), R56.2, U4.9 (-)
unnamed: D5.1 (K), D6.2 (A), U2.8
unnamed: D5.2 (A), D6.1 (K), R22.2, U2.9 (-)
unnamed: D7.1 (K), D8.2 (A), U5.8
unnamed: D7.2 (A), D8.1 (K), R52.2, U5.9 (-)
unnamed: J1.T, R3.2
unnamed: J1.TN, R6.1
unnamed: J2.T, R20.2
unnamed: J3.T, R32.2
unnamed: J3.TN, R35.1
unnamed: J5.T, R50.2
unnamed: J6.T, R12.1
unnamed: J6.TN, R7.1
unnamed: J7.T, R42.1
unnamed: J7.TN, R26.1
unnamed: R1.1, R15.1, U3.2 (I_IN1)
unnamed: R4.1, R5.2, U2.1
unnamed: R4.2, U2.2 (-), U3.5 (I_OUT2)
unnamed: R7.2, R8.1, U2.13 (-)
unnamed: R13.1, RV1.5
unnamed: R14.1, R19.2, U2.10 (+)
unnamed: R9.1, R16.2, U3.7 (I_IN2)
unnamed: R18.2, R23.1, U1.14
unnamed: R20.1, RV1.2
unnamed: R23.2, RV1.3, U1.13 (-)
unnamed: R24.1, R27.2, U1.10 (+)
unnamed: J4.1, R25.2
unnamed: R8.2, R29.2, U2.14
unnamed: R30.1, R45.1, U3.10 (I_IN3)
unnamed: R33.1, R34.2, U5.1
unnamed: R33.2, U3.13 (I_OUT4), U5.2 (-)
unnamed: R38.1, R46.2, U3.15 (I_IN4)
unnamed: R41.1, U3.1 (MODE)
unnamed: R43.1, RV2.5
unnamed: R44.1, R49.2, U5.10 (+)
unnamed: R48.2, R53.1, U4.14
unnamed: R50.1, RV2.2
unnamed: R53.2, RV2.3, U4.13 (-)
unnamed: R54.1, R55.2, U4.10 (+)
unnamed: R26.2, R36.1, U5.13 (-)
unnamed: J8.1, R36.2, U5.14
VCC: R41.2, U3.16 (V+); also elsewhere on the board
VEE: U3.9 (V-); also elsewhere on the board

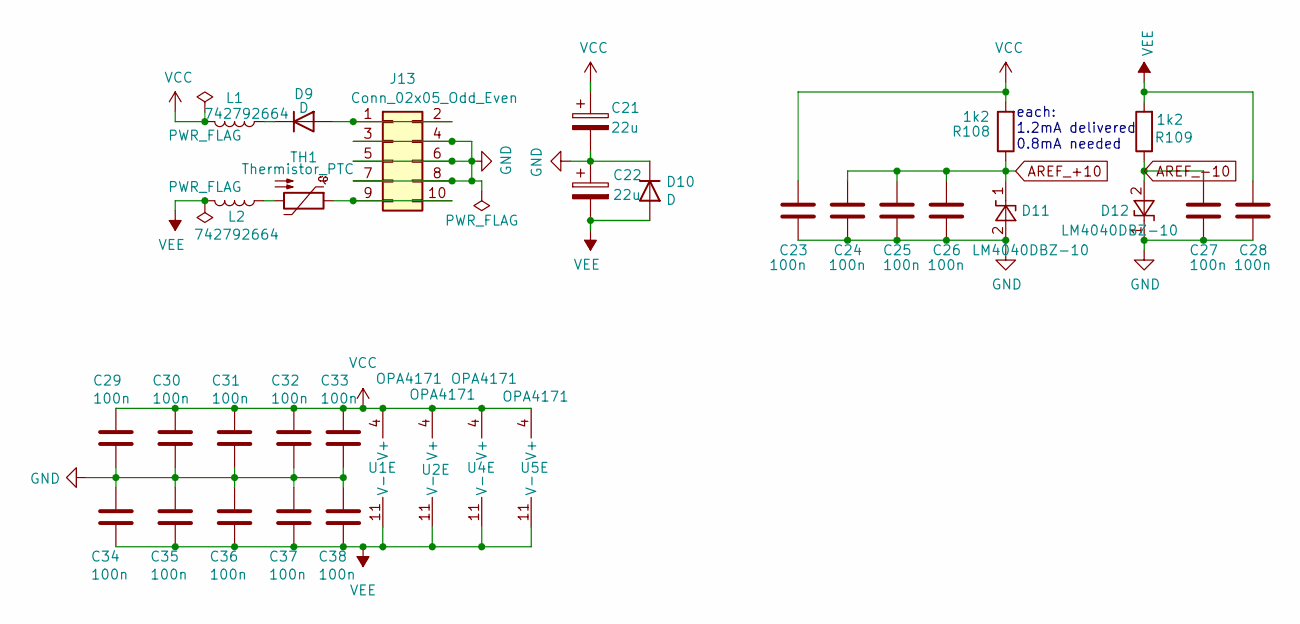
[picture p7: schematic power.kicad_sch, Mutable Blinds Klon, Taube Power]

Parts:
C21, C22: 22u; CP_Radial_D5.0mm_P2.50mm
C23, C24, C25, C26, C27, C28, C29, C30, C31, C32, C33, C34, C35, C36, C37, C38: 100n; C_0805_2012Metric_Pad1.18x1.45mm_HandSolder
D9, D10: D; D_SMA_Handsoldering
D11, D12: LM4040DBZ-10; SOT-23_Handsoldering
J13: Conn_02x05_Odd_Even; PinHeader_2x05_P2.54mm_Vertical
L1, L2: 742792664; L_0603_1608Metric_Pad1.05x0.95mm_HandSolder
R108, R109: 1k2; R_0805_2012Metric_Pad1.20x1.40mm_HandSolder
TH1: Thermistor_PTC; R_1206_3216Metric_Pad1.30x1.75mm_HandSolder
U1, U2, U4, U5: OPA4171; SOIC-14_3.9x8.7mm_P1.27mm

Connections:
AREF_+10: C24.2, C25.2, C26.2, D11.1 (K), R108.1; also elsewhere on the board
AREF_-10: C27.2, D12.2 (A), R109.1; also elsewhere on the board
GND: C21.2, C22.1, C23.1, C24.1, C25.1, C26.1, C27.1, C28.1, C29.1, C30.1, C31.1, C32.1, C33.1, C34.2, C35.2, C36.2, C37.2, C38.2, D10.1 (K), D11.2 (A), D12.1 (K), J13.3, J13.4, J13.5, J13.6, J13.7, J13.8; also elsewhere on the board
unnamed: D9.1 (K), L1.1
unnamed: D9.2 (A), J13.1, J13.2
unnamed: J13.9, J13.10, TH1.1
unnamed: L2.1, TH1.2
VCC: C21.1, C23.2, C29.2, C30.2, C31.2, C32.2, C33.2, L1.2, R108.2, U1.4 (V+), U2.4 (V+), U4.4 (V+), U5.4 (V+); also elsewhere on the board
VEE: C22.2, C28.2, C34.1, C35.1, C36.1, C37.1, C38.1, D10.2 (A), L2.2, R109.2, U1.11 (V-), U2.11 (V-), U4.11 (V-), U5.11 (V-); also elsewhere on the board

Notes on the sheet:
each: 1.2mA delivered 0.8mA needed

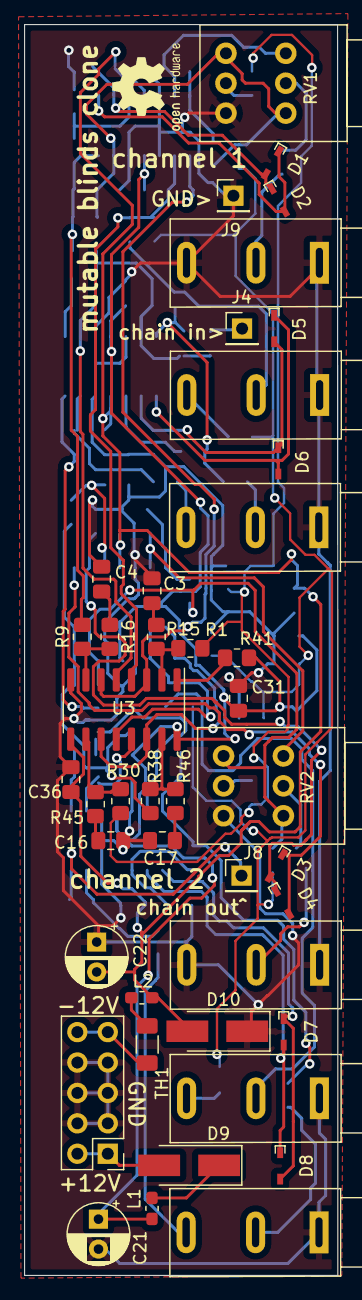
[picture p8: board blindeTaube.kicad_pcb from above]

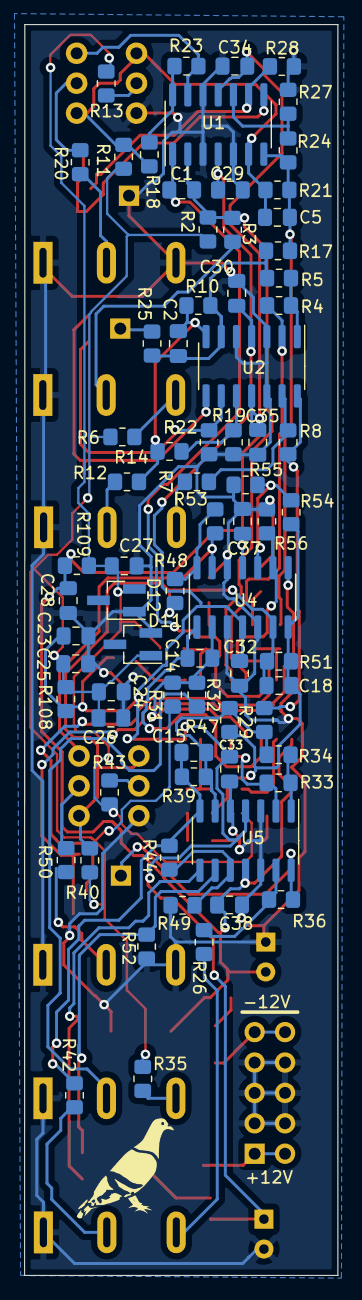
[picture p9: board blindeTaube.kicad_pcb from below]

Board: 2 copper layers, 26.2 x 104.5 mm, 117 parts (74 on the bottom side), 69 nets.

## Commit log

2022-08-12 add Version 1 and Version 2 of the Polarizer KiCad-Projects
    [Kanal3+4.kicad_sch, Kanal3+4.sch, blindeTaube-BU1Kanal.sch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]
2022-08-12 insert 3D-Screenshots into Readme
2022-08-15 move potentiometers a little bit to the edge of the board
    [blindeTaube.kicad_pcb]
